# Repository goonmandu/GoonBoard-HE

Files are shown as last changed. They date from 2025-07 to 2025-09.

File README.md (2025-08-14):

# GoonBoard-HE
## Overview
This repository contains the firmware source code for building a USB HID keyboard with the Pro Micro development board using hall-effect switches.

The web configurator companion is [GoonBoard-Configurator](https://github.com/goonmandu/GoonBoard-Configurator).

## Features
- 1000 Hz polling rate
- Rapid trigger
- SnapTap (two modules)
- Full on-the-fly reconfigurability for:
  - Keymaps
  - Actuation points per key
  - Rapid trigger enable/sensitivity
  - SnapTap enable/keys
- NKRO Support

## Parts used
| Type | Manufacturer | Part Number | Unit Price (USD) |
|---|---|---|---|
| ADC | TI | ADS7885 | 3.67 |
| Microcontroller | Microchip | ATmega32U4 | 5.29 |
| Multiplexer | TI | CD74HC4067M96 | 0.65 |
| HE Sensor | Nanjing Ouzhuo Tech  | OH49E-S | 0.18 |
| HE Switch | Gateron | KS-20T (90 pcs) | 57.60 |
| Rotary Encoder  | Alps | EC11 | 1.99 |

## Compiling and Uploading
Since I have used the PlatformIO toolchain for the entirety of the development process, the steps using PlatformIO will be shared.

1. Install Visual Studio Code.
2. Install the PlatformIO extension.
3. Open the `GoonBoard-HE` workspace.
4. Click on the `PlatformIO: Build` button.
5. Click on the `PlatformIO: Upload` button.
6. Put your microcontroller into DFU mode by shorting `RST` and `GND`.
7. Wait a few seconds and your microcontroller will be recognized as `GoonMandu GoonBoard` with VID:PID `2B00:B1E5`.

## Performance
Tested with ATmega32U4 @ 16 MHz, target polling rate 1000 Hz, both SnapTap modules enabled.

Reference release: [V3.250814.0](https://github.com/goonmandu/GoonBoard-HE/releases/tag/V3.250814.0)

| Metric | RT On | RT Off |
|-|-|-|
| Start polling to sending HID report | 760 us | 730 us |
| 1000 Hz polling rate compliance | ✅ | ✅ |

## Pin Assignments
| AVR | Pro Micro | Function | Notes |
|-|-|-|-|
| PD0 | TXO | Row Mux S0 |
| PD1 | RXI | Row Mux S1 |
| PD2 | 2 | Row Mux S2 |
| PD3 | 3 | Row Mux S3 |
| PF4 | A3 | Key Mux S0 |
| PF5 | A2 | Key Mux S1 |
| PF6 | A1 | Key Mux S2 |
| PF7 | A0 | Key Mux S3 |
| PD4 | 4 | Knob "CLK" | aka signal "A", pulled high |
| PD7 | 6 | Knob "DT" | aka signal "B", pulled high |
| PC6 | 5 | Knob Button | pulled high |
| PE6 | 7 | Caps Lock LED |
| PB4 | 8 | Num Lock LED |
| PB5 | 9 | Scr Lock LED | used as debug bit if<br>`DEBUG_BITS` is defined. |
| PB6 | 10 | SPI /SS |
| PB3 | 14 | SPI MISO |
| PB1 | 15 | SPI SCLK |

## Versioning
Format:
```
V{compat}.{YY}{MM}{DD}.{n}
```
- `compat`: Integer. This changing means that the hardware/timing compatibility or pin assignments have changed and is not physically compatible with other `compat` versions.
- `YY`: Two-digit year.
- `MM`: Zero-padded month.
- `DD`: Zero-padded day.
- `n`: Integer. Release number in the same day.

## Maintenance? PRs? Issues?
I will not be paying much attention to this repository once I have implemented the features I want so they will probably be ignored. If you want to build upon this repository and want clarification, *please* feel free to annoy me at:

Discord: `goonmandu`<br>
Email: `hwang [dot] mingi7 [at] gmail [dot] com`

## Acknowledgements and Open-Source Licenses
All files under `src/` that do not contain a license header are licensed under the MIT License, Copyright (c) 2025 Mingi Hwang.

This firmware is built upon the Keyboard demo from the LUFA repository:
- [LUFA](https://github.com/abcminiuser/lufa):
    ```
    LUFA Library
    Copyright (C) Dean Camera, 2021.

    dean [at] fourwalledcubicle [dot] com
    www.lufa-lib.org

    Permission to use, copy, modify, and distribute this software and its documentation for any purpose is hereby granted without fee, provided that the above copyright notice appear in all copies and that both that the copyright notice and this permission notice and warranty disclaimer appear in supporting documentation, and that the name of the author not be used in advertising or publicity pertaining to distribution of the software without specific, written prior permission.

    The author disclaims all warranties with regard to this software, including all implied warranties of merchantability and fitness.  In no event shall the author be liable for any special, indirect or consequential damages or any damages whatsoever resulting from loss of use, data or profits, whether in an action of contract, negligence or other tortious action, arising out of or in connection with the use or performance of this software.
    ```

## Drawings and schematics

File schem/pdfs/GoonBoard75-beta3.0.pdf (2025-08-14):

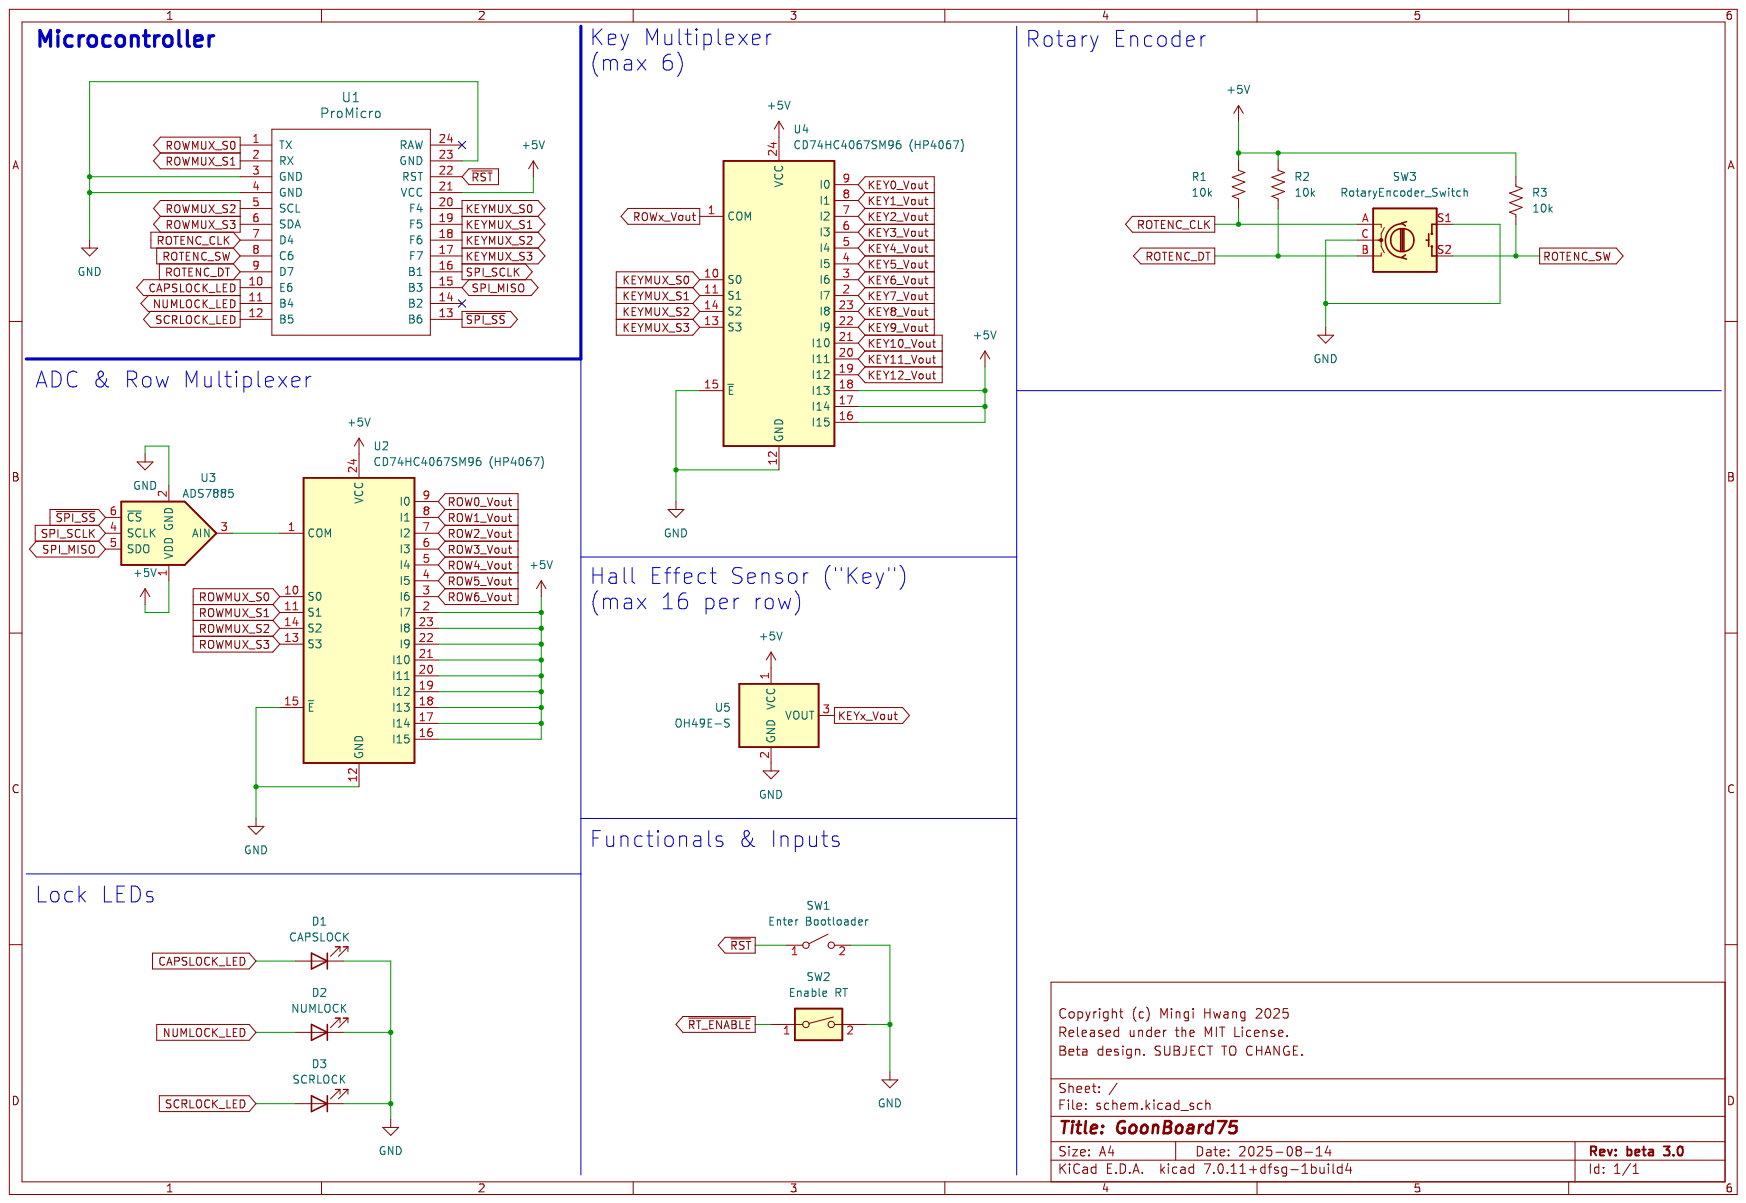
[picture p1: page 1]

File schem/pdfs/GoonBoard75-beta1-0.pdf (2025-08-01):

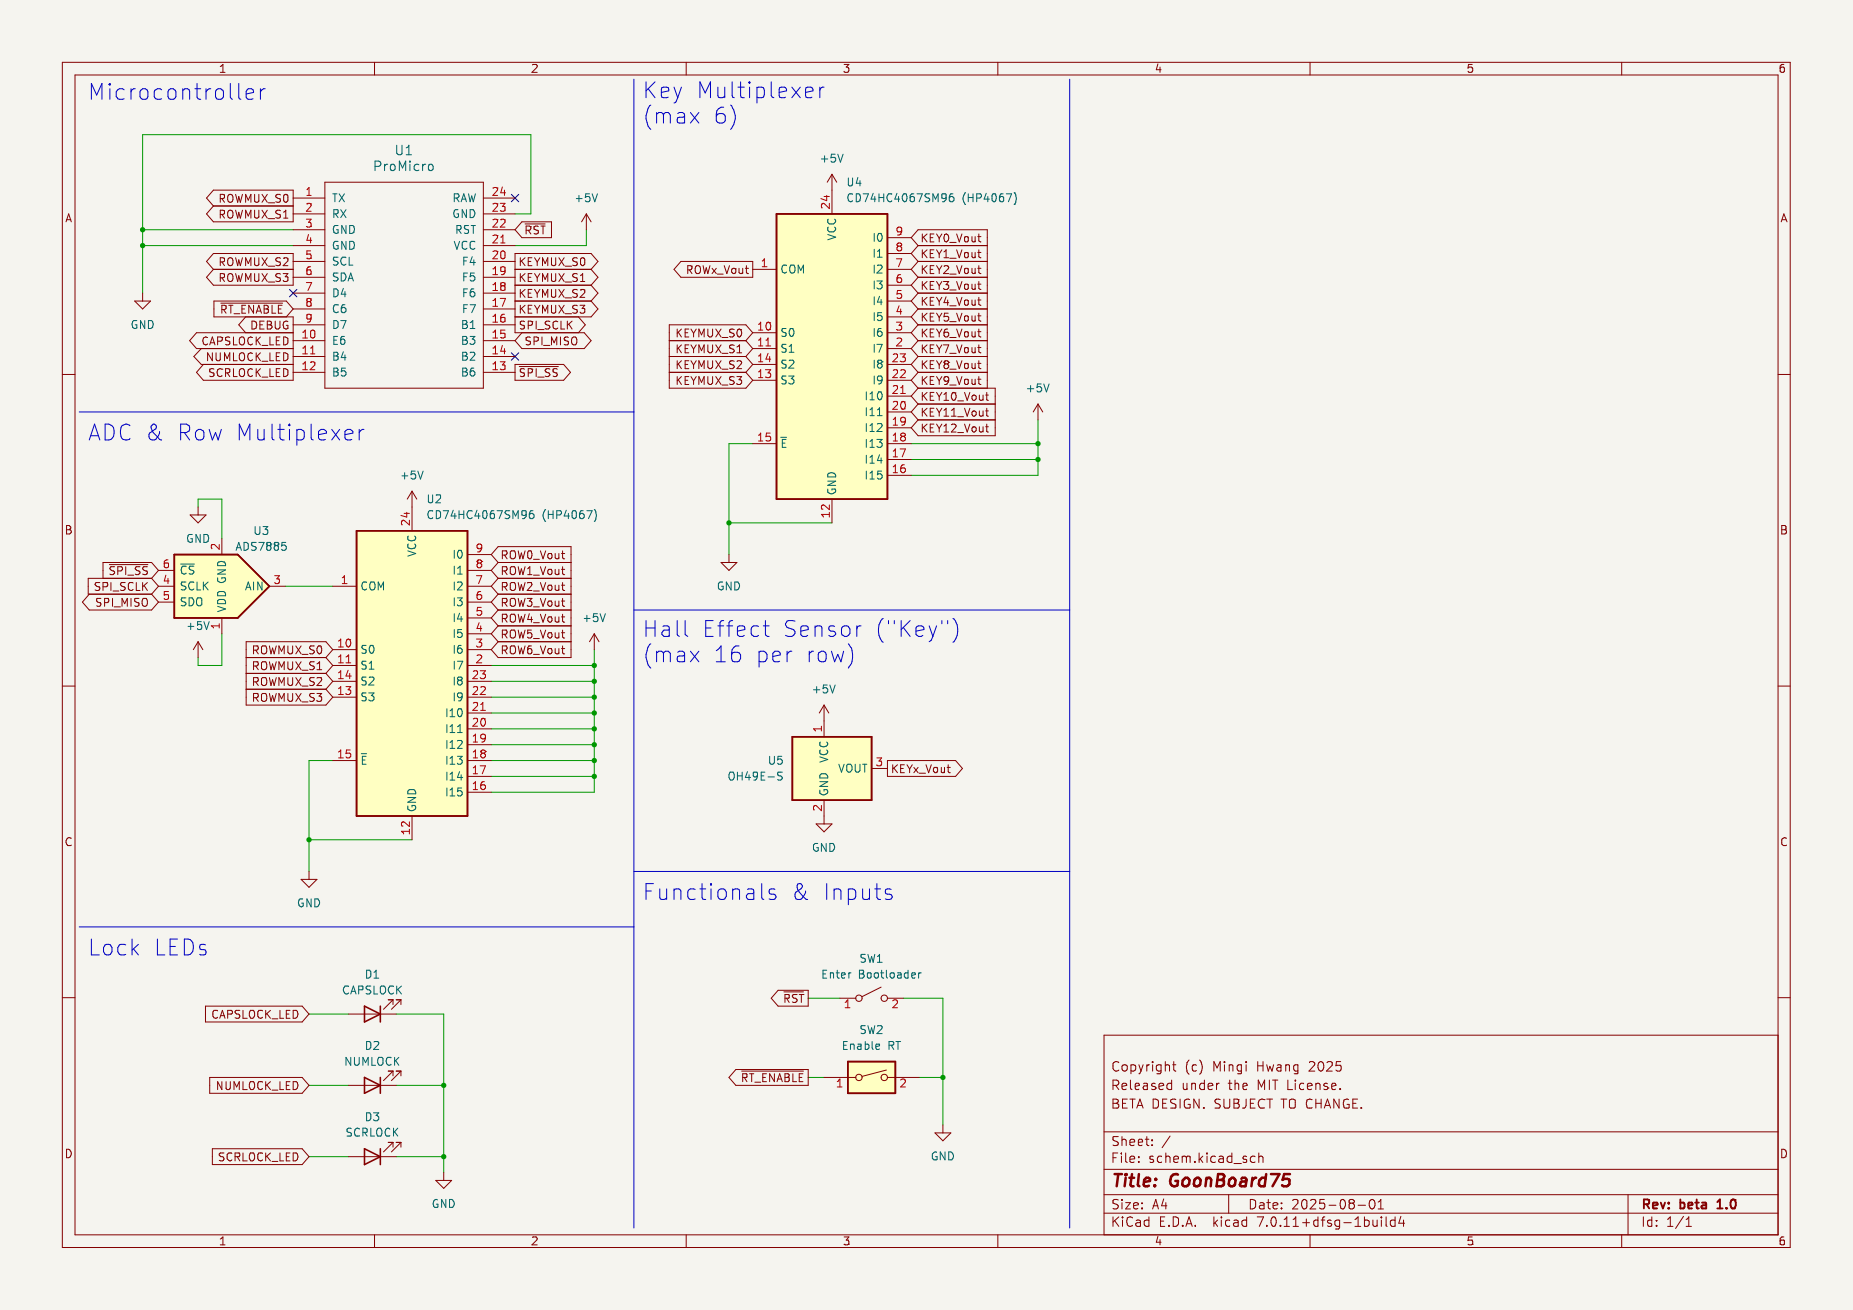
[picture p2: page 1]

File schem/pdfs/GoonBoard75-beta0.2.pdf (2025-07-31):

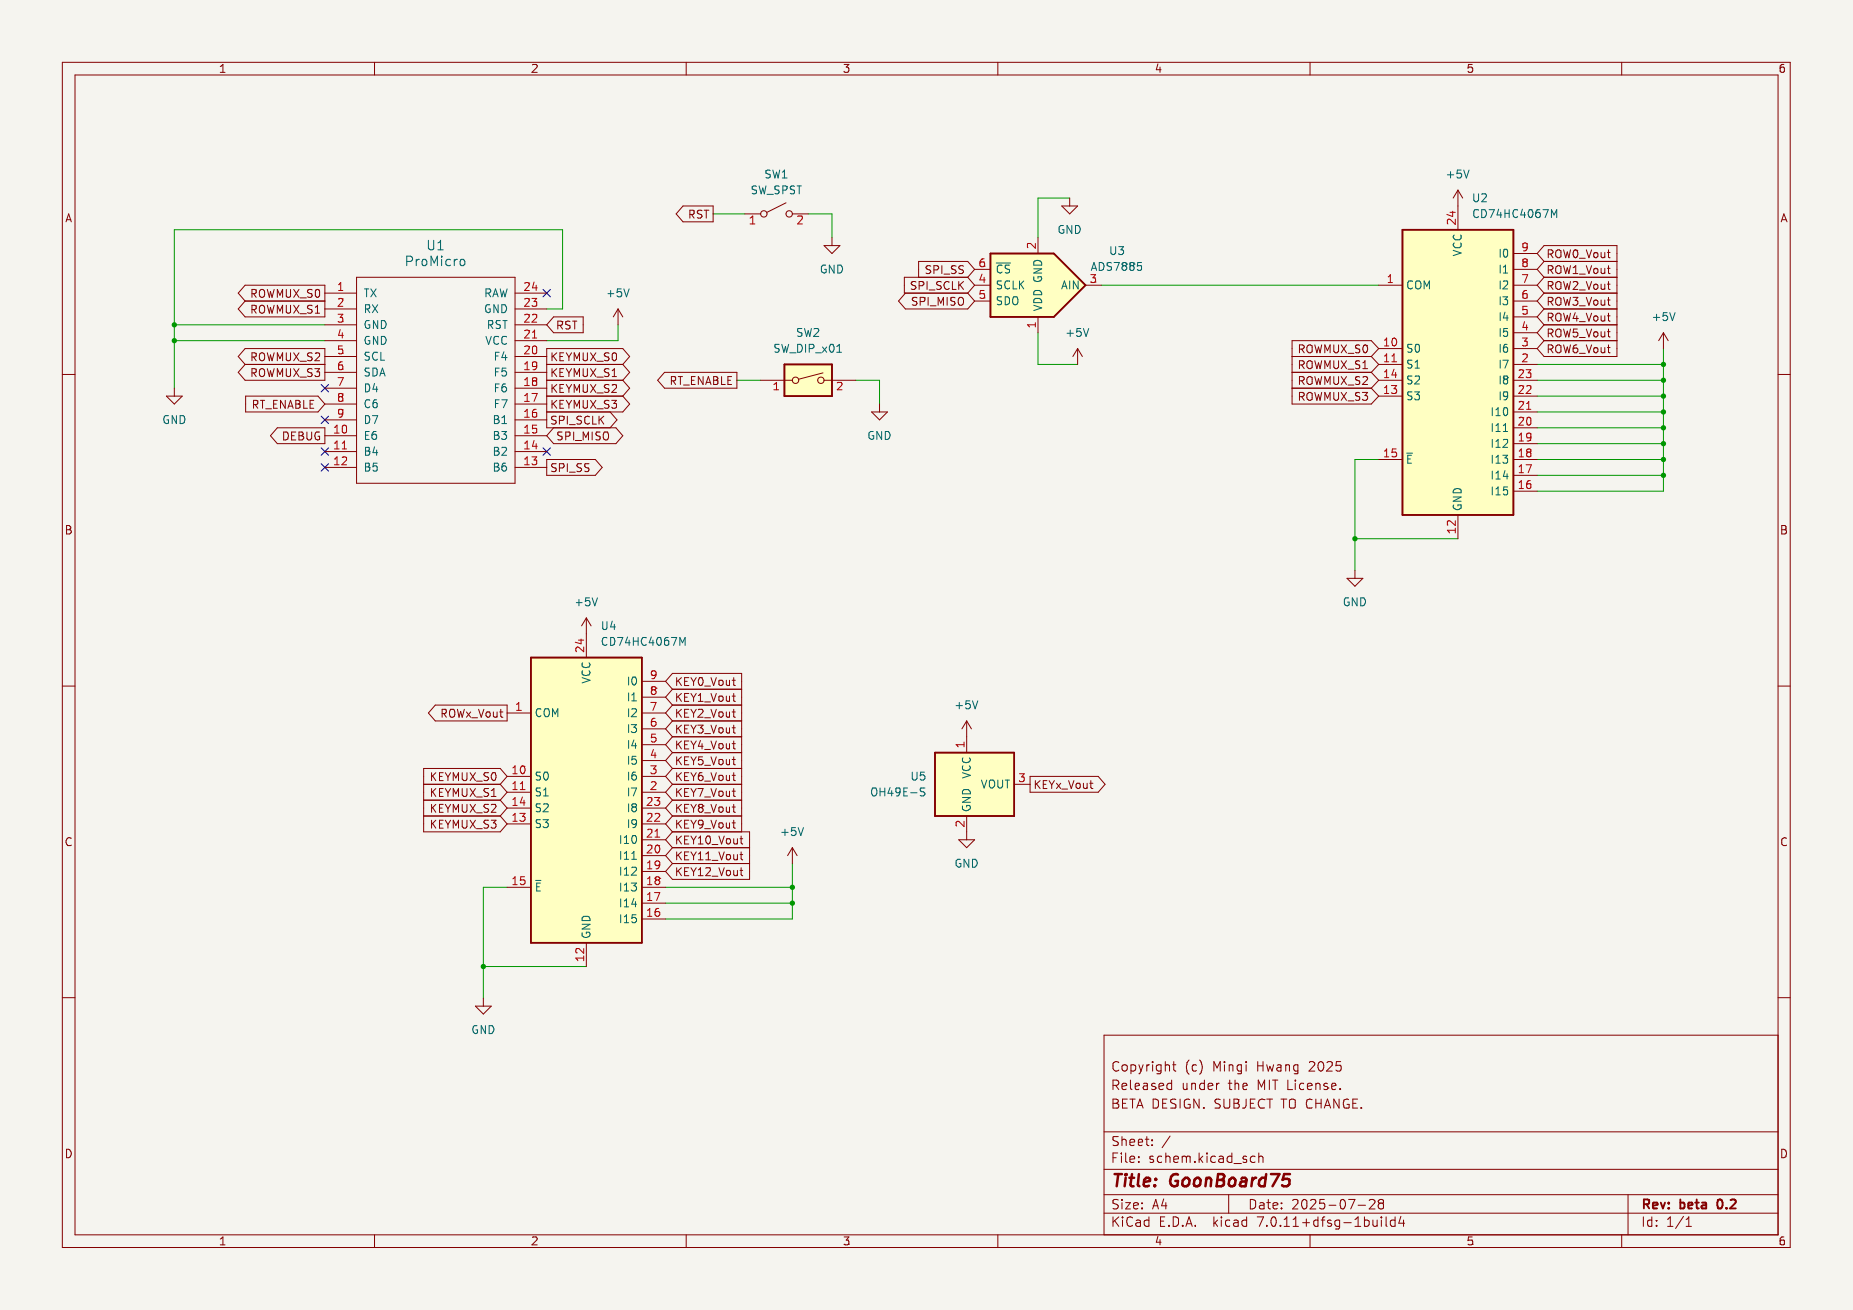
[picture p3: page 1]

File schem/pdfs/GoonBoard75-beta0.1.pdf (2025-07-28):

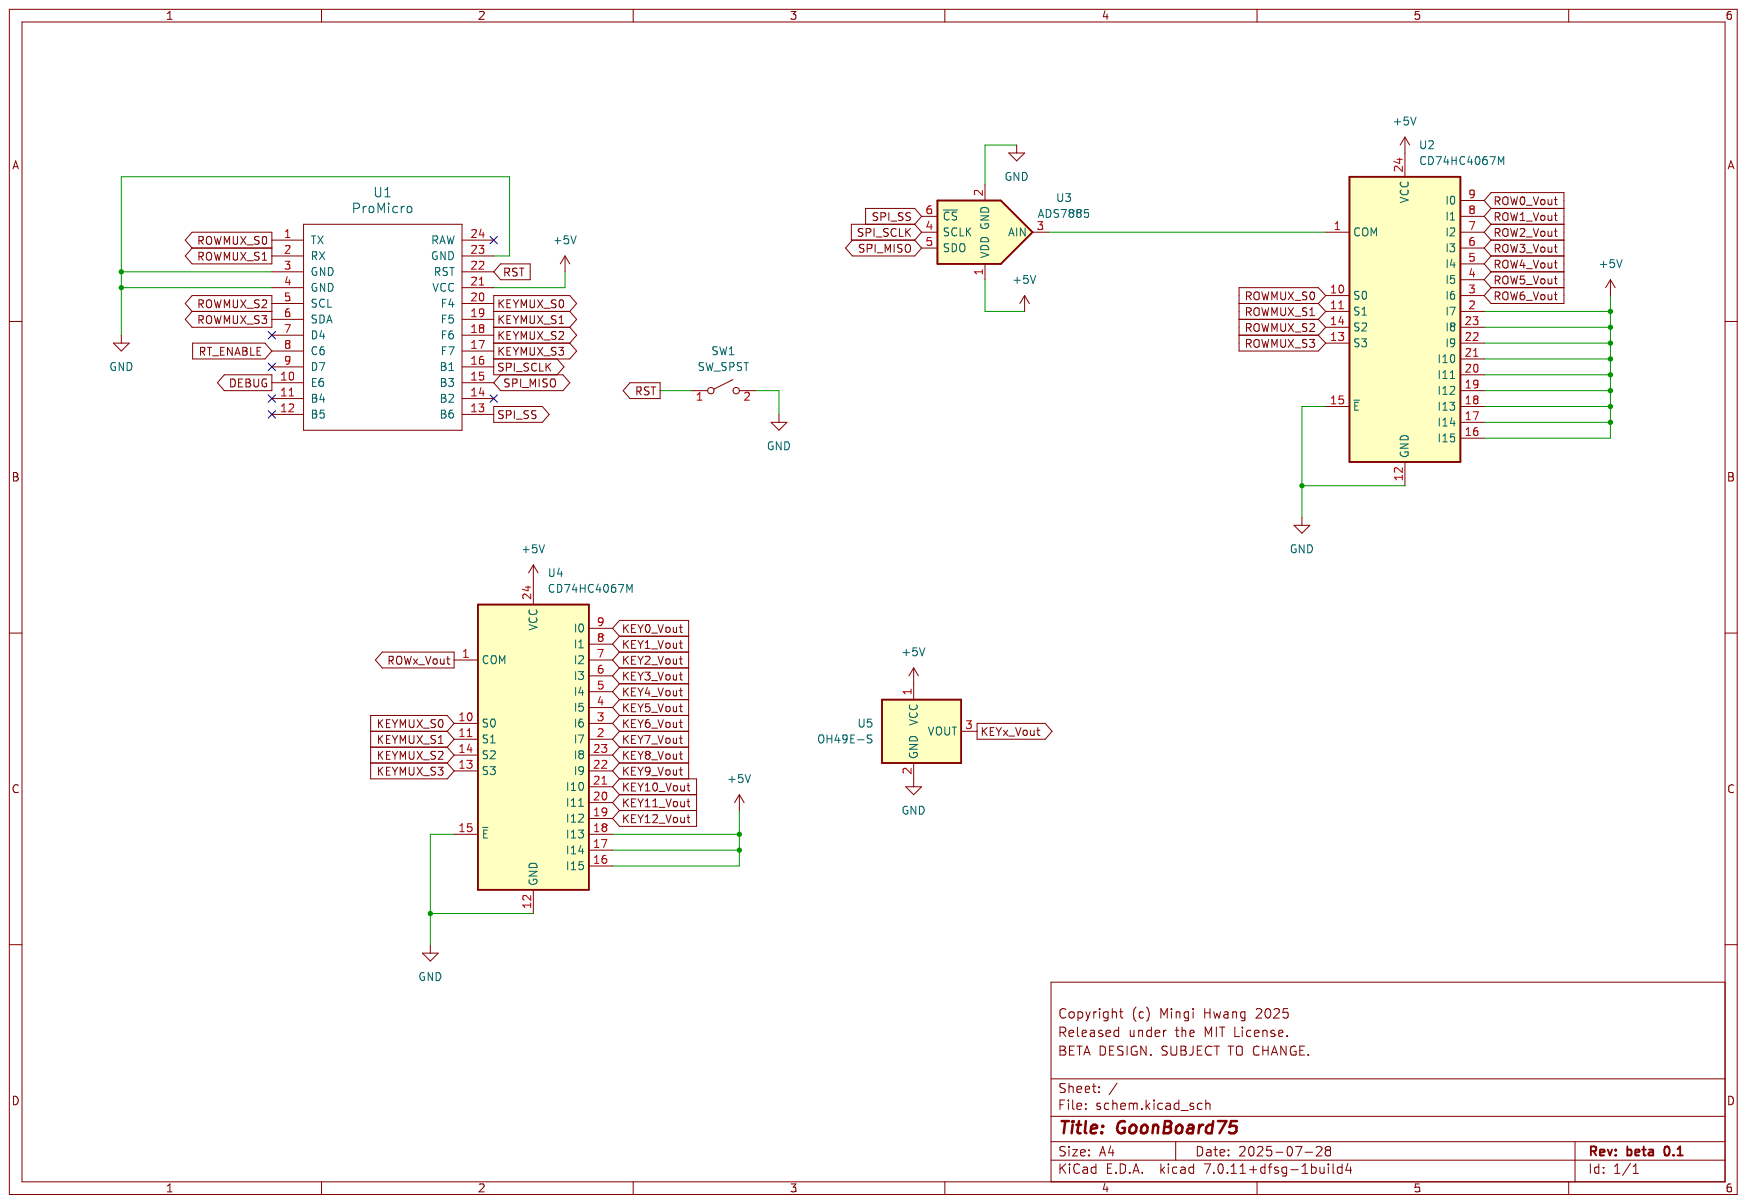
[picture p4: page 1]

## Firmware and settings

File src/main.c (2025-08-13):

#include "Keyboard.h"
#include "SPI.h"
#include "I2C.h"
#include "MatrixScanner.h"
#include "Hacks.h"
#include "SettingsEditor.h"

extern uint8_t PrevKeyboardHIDReportBuffer[PREV_REPORT_BUFFER_SIZE];
extern USB_ClassInfo_HID_Device_t Keyboard_HID_Interface;
extern USB_ClassInfo_HID_Device_t RawHID_HID_Interface;

int main(void) {
    SetupHardware();

    DEBUG_BIT_PIN_CONFIG;
    CLEAR_DEBUG_BIT;

    spi_init_master();
    setup_mux_pins();
    setup_led_pins();

    load_eeprom_to_sram();
    measure_adc_baseline();

    // Configure rotary encoder input pins
    DDRD &= ~ROTARY_MASK;
    DDRC &= ~(1 << ROTARY_SIGPB);

    // Turn off Pro Micro TX/RX LEDs
    DDRB |= (1 << PB0);
    DDRD |= (1 << PD5);
    PORTB |= (1 << PB0);
    PORTD |= (1 << PD5);
    
    GlobalInterruptEnable();

    while (1) {
        SET_DEBUG_BIT;
        // This is the keyboard generating its OWN report
        // every 1 ms (because the firmware is 1000 Hz).
        HID_Device_USBTask(&Keyboard_HID_Interface);
        HID_Device_USBTask(&RawHID_HID_Interface);
        CLEAR_DEBUG_BIT;

        // This is polled continuously (because HID_Device_USBTask
        // exits early if there is no data to send) to serviceUSB requests
        // USB requests from the host.
        USB_USBTask();
    }
}

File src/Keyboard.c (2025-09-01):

/*
             LUFA Library
     Copyright (C) Dean Camera, 2021.

  dean [at] fourwalledcubicle [dot] com
           www.lufa-lib.org
*/

/*
  Copyright 2021  Dean Camera (dean [at] fourwalledcubicle [dot] com)

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
  The author disclaims all warranties with regard to this
  software, including all implied warranties of merchantability
  and fitness.  In no event shall the author be liable for any
  special, indirect or consequential damages or any damages
  whatsoever resulting from loss of use, data or profits, whether
  in an action of contract, negligence or other tortious action,
  arising out of or in connection with the use or performance of
  this software.
*/

/** \file
 *
 *  This file contains the main tasks of the keyboard and is responsible for the 
 *  initial application hardware configuration.
 */


#include "Keyboard.h"
#include "SPI.h"
#include "I2C.h"
#include "MatrixScanner.h"
#include "SettingsEditor.h"
#include "DefaultSettings.h"
#include "Hacks.h"
#include "SnapTap.h"
#include "Keycodes.h"

/** Buffer to hold the previously generated Keyboard HID report, for comparison purposes inside the HID class driver. */
uint8_t PrevKeyboardHIDReportBuffer[PREV_REPORT_BUFFER_SIZE];

/* START CUSTOMIZATION CODE */

// Variables to detect keypresses
extern uint8_t key_status[NUM_ROWS][MAX_KEYS_SUPPORTED_PER_ROW];
uint8_t rotary_now = ROTARY_STATE_A;
uint8_t rotary_prev = ROTARY_STATE_A;
int8_t rotary_counts = 0;

/* END CUSTOMIZATION CODE */

/** LUFA HID Class driver interface configuration and state information. This structure is
 *  passed to all HID Class driver functions, so that multiple instances of the same class
 *  within a device can be differentiated from one another.
 */
USB_ClassInfo_HID_Device_t Keyboard_HID_Interface =
    {
        .Config =
            {
                .InterfaceNumber                = INTERFACE_ID_Keyboard,
                .ReportINEndpoint               =
                    {
                        .Address                = KEYBOARD_EPADDR,
                        .Size                   = KEYBOARD_EPSIZE,
                        .Banks                  = 2,  // One for KB/KP report, and another for Cons Ctrl report
                    },
                .PrevReportINBuffer             = PrevKeyboardHIDReportBuffer,
                .PrevReportINBufferSize         = sizeof(PrevKeyboardHIDReportBuffer),
            },
    };

USB_ClassInfo_HID_Device_t RawHID_HID_Interface = 
    {
        .Config =
            {
                .InterfaceNumber                = INTERFACE_ID_RawHID,
                .ReportINEndpoint               =
                    {
                        .Address                = RAWHID_IN_EPADDR,
                        .Size                   = RAWHID_IN_EPSIZE,
                        .Banks                  = 1,
                    },
                .PrevReportINBuffer             = NULL,  // monkaS bare metal nullptr dereference
                .PrevReportINBufferSize         = sizeof(default_settings),
            },
    };

/** Configures the board hardware and chip peripherals for the demo's functionality. */
void SetupHardware()
{
#if (ARCH == ARCH_AVR8)
    /* Disable watchdog if enabled by bootloader/fuses */
    MCUSR &= ~(1 << WDRF);
    wdt_disable();

    /* Disable clock division */
    clock_prescale_set(clock_div_1);
#elif (ARCH == ARCH_XMEGA)
    /* Start the PLL to multiply the 2MHz RC oscillator to 32MHz and switch the CPU core to run from it */
    XMEGACLK_StartPLL(CLOCK_SRC_INT_RC2MHZ, 2000000, F_CPU);
    XMEGACLK_SetCPUClockSource(CLOCK_SRC_PLL);

    /* Start the 32MHz internal RC oscillator and start the DFLL to increase it to 48MHz using the USB SOF as a reference */
    XMEGACLK_StartInternalOscillator(CLOCK_SRC_INT_RC32MHZ);
    XMEGACLK_StartDFLL(CLOCK_SRC_INT_RC32MHZ, DFLL_REF_INT_USBSOF, F_USB);

    PMIC.CTRL = PMIC_LOLVLEN_bm | PMIC_MEDLVLEN_bm | PMIC_HILVLEN_bm;
#endif

    USB_Init();
}

/** Event handler for the library USB Connection event. */
void EVENT_USB_Device_Connect(void)
{
    // LEDs_SetAllLEDs(LEDMASK_USB_ENUMERATING);
}

/** Event handler for the library USB Disconnection event. */
void EVENT_USB_Device_Disconnect(void)
{
    // LEDs_SetAllLEDs(LEDMASK_USB_NOTREADY);
}

/** Event handler for the library USB Configuration Changed event. */
void EVENT_USB_Device_ConfigurationChanged(void)
{
    bool ConfigSuccess = true;

    ConfigSuccess &= HID_Device_ConfigureEndpoints(&Keyboard_HID_Interface);
    ConfigSuccess &= HID_Device_ConfigureEndpoints(&RawHID_HID_Interface);

    USB_Device_EnableSOFEvents();
}

/** Event handler for the library USB Control Request reception event. */
void EVENT_USB_Device_ControlRequest(void)
{
    HID_Device_ProcessControlRequest(&Keyboard_HID_Interface);
    HID_Device_ProcessControlRequest(&RawHID_HID_Interface);
}
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

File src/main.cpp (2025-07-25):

#include "Keyboard.h"
#include "SPI.h"
#include "I2C.h"
#include "MatrixScanner.h"

extern uint8_t PrevKeyboardHIDReportBuffer[sizeof(USB_KeyboardReport_Data_t)];
extern USB_ClassInfo_HID_Device_t Keyboard_HID_Interface;

int main(void) {
    SetupHardware();

    // Turn off Pro Micro TX/RX LEDs
    DDRB |= (1 << PB0);
    DDRD |= (1 << PD5);
    PORTB |= (1 << PB0);
    PORTD |= (1 << PD5);

    // DDRD |= (1 << PD4);

    // PC6 is Rapid-Trigger Enable
    DDRC &= ~(1 << PC6);  // Set PC6 as input
    PORTC |= (1 << PC6);  // Enable pull-up

    spi_init_master();
    setup_mux_pins();

    measure_adc_baseline();
    
    GlobalInterruptEnable();

    while (1) {
        HID_Device_USBTask(&Keyboard_HID_Interface);
        USB_USBTask();
    }
}

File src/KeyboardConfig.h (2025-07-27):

#ifndef KEYBOARDCONFIG_H
#define KEYBOARDCONFIG_H

#include "Keyboard.h"

// This is defined as the required keypress depth.
// For example, MM(0.5) means you have to press the key 0.5 mm for it to register as a press.
// Valid range: 0.1 - 3.4 (for Gateron "Magnetic Jade Shaft" KS-20T switches)
// ADC baselines when switch makes physical contact with sensor: 
//     104 (0x68) when switch is fully released.
//      68 (0x22) when switch is fully pressed.
// Conversion factor: 1 ADC bit ≈ 0.1 mm travel for KS-20T.
//
// Notes:
//   - Total travel: 3.5 mm
//     (104 - 68) / 35 = ~1.03 bits per 0.1 mm
//     Rounded to 1 bit per 0.1 mm for simplicity
#define MM(MILLIMETERS) ((uint8_t)(MILLIMETERS*10))

// Each USB frame happens every 1 ms.
#define MS(MILLISECONDS) (MILLISECONDS)

// Refer to "lib/LUFA/Drivers/USB/Class/Common/HIDClassCommon.h" for the key names.
// The KEY(NAME) macro just appends "HID_KEYBOARD_SC_" to the NAME argument.
#define HID_KEYBOARD_NO 0x00
#define KEY(NAME) HID_KEYBOARD_SC_##NAME



/***************************************************
 *      ┌──────────────────────────────────┐       *
 *      | KEYBOARD CONFIGURATION CONSTANTS |       *
 *      └──────────────────────────────────┘       *
 * Please read the stuff ^^up there^^ first before *
 *            doing any configuration!             *
 ***************************************************/


/***************************************************
 * NUM_KEYS: How many keys on your keyboard?       *
 * Minimum:  1                                     *
 * Maximim: 16                                     *
 ***************************************************
 * Notes: If you change this, make sure to also    *
 *        change the number of elements on the     *
 *        keymap and actuation arrays!             *
 ***************************************************/
#define MAX_KEYS_SUPPORTED_PER_ROW 16
#define NUM_ROWS 6
const uint8_t NUM_KEYS_PER_ROW[NUM_ROWS] = {
    13, 15, 15, 14, 14, 10  // 75%, 81 keys
};

/*
#define NUM_ROWS 5
#define MAX_KEYS_SUPPORTED_PER_ROW 16
const uint8_t NUM_KEYS_PER_ROW[NUM_ROWS] = {
    15, 15, 14, 14, 10  // 65%, 68 keys
};
 */


/****************************************************
 * KEYMAP: Map which MUX channel to which keycode?  *
 ****************************************************
 * Notes: Make sure the number of keycodes in this  *
 *        array matches NUM_KEYS!                   *
 *        The first entry maps to C0, second C1,    *
 *        and so on.                                *
 ****************************************************/
const uint8_t KEYMAP_MATRIX[NUM_ROWS][MAX_KEYS_SUPPORTED_PER_ROW] = {
    {KEY(Q), KEY(W), KEY(E), KEY(LEFT_SHIFT)},
    {KEY(R), KEY(T), KEY(Y), KEY(SPACE)},
    {KEY(A), KEY(S), KEY(D)},
    {KEY(F), KEY(G), KEY(H)},
    {KEY(Z), KEY(X), KEY(C)},
    {KEY(V), KEY(B), KEY(N)}
};


/****************************************************
 * COMMON_ACTUATION: Actuation point for all keys?  *
 * Minimum: MM(0.1)                                 *
 * Maximim: MM(3.4)                                 *
 ****************************************************
 * Notes: This is specific to Gateron Jade stems,   *
 *        which have a 3.5mm travel distance.       *
 *        Uncomment USE_COMMON_ACTUATION to enable  *
 *        common actuation instead of per-key       *
 *        actuation.                                *
 ****************************************************/
#define USE_COMMON_ACTUATION
#define COMMON_ACTUATION \
        MM(1.5)


/****************************************************
 * ACTUATIONS: Actuation point for each key?        *
 ****************************************************
 * Notes: Make sure the number of actuation points  *
 *        in this array matches NUM_KEYS!           *
 *        The first entry maps to C0, second C1,    *
 *        and so on.                                *
 ****************************************************/
#ifndef USE_COMMON_ACTUATION
const uint8_t ACTUATIONS[NUM_KEYS] = {
    MM(1.0),
    MM(1.5),
    MM(2.0),
    MM(2.5),
};
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

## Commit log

2025-07-21 Fixed actuation and RT buggy prototype
    [Descriptors.h, Keyboard.c, Keyboard.h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]
2025-07-23 Rapid trigger functional(?) prototype
2025-07-23 Avoid one level of indentation
    [MatrixScanner.h]
2025-07-24 Add pin and versioning info
2025-07-25 Mux matrix 6x16 Prototype
2025-07-28 USB 1000 Hz compliance
2025-07-28 Add schematics
2025-07-28 Add schematics, 2nd try
    [schem.kicad_pcb, schem.kicad_sch]
2025-07-29 Caps/Num/Scr lock status LEDs
    [schem.kicad_sch]
2025-07-30 Swap ptrs instead of writing old_values byte-by-byte
    [Keyboard.c, MatrixScanner.c, MatrixScanner.h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]
2025-07-31 Restructure ADC read loop to be compliant with Mux timings
    [schem.kicad_sch]
2025-08-01 Optimize SPI read routine with inline asm
    [schem.kicad_sch]
2025-08-01 Second SnapTap module and SnapTap HID API
    [Descriptors.h, Keyboard.c, KeyboardConfig.h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]
2025-08-04 Potential fix for noncompliant USB HID descriptor
    [Descriptors.h, Keyboard.c, Keyboard.h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]
2025-08-11 Fix noncompliant RawHID IN EP size
    [Descriptors.h]
2025-08-13 Add rotary encoder
2025-08-14 Add rotary encoder to and remove RT switch from schematic
    [schem.kicad_sch]
2025-08-16 Enable double banking to avoid waiting for endpoint clear
    [Keyboard.c]
2025-09-01 Fix LEDs report ID mismatch
    [Keyboard.c]
